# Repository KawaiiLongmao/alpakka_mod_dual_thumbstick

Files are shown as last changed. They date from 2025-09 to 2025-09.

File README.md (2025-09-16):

Development Board : rp2040 zero

初版：

GP20(Home)->GP13,GP18(CS0)->GP0,GP19(CS1)->GP1

led：上移12.5mm

r6电阻：左移21.5mm，上移4.75mm

home：上移22.5mm

滚轮：左移16mm

两摇杆间距：51.75mm

修订1：

GP20(Home)->GP13,GP18(CS0)->GP0,GP19(CS1)->GP1

led：上移12.5mm

r6电阻：左移21.5mm，上移4.75mm

home：上移22.5mm

滚轮：左移18.5mm

左摇杆：左移2.5mm

两摇杆间距：52mm

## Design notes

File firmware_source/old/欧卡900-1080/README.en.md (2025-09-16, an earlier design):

# 小改alpakka固件

#### Description
{**When you're done, you can delete the content in this README and update the file with details for others getting started with your repository**}

#### Software Architecture
Software architecture description

#### Installation

1.  xxxx
2.  xxxx
3.  xxxx

#### Instructions

1.  xxxx
2.  xxxx
3.  xxxx

#### Contribution

1.  Fork the repository
2.  Create Feat_xxx branch
3.  Commit your code
4.  Create Pull Request

#### Gitee Feature

1.  You can use Readme\_XXX.md to support different languages, such as Readme\_en.md, Readme\_zh.md
2.  Gitee blog [blog.gitee.com](https://blog.gitee.com)
3.  Explore open source project [https://gitee.com/explore](https://gitee.com/explore)
4.  The most valuable open source project [GVP](https://gitee.com/gvp)
5.  The manual of Gitee [https://gitee.com/help](https://gitee.com/help)
6.  The most popular members  [https://gitee.com/gitee-stars/](https://gitee.com/gitee-stars/)

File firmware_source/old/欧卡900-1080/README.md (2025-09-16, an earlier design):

欧卡固件：

为了兼容官方网页，方向盘角度是网页配置数值的6倍。

原本就有的问题：建议这么垫在键盘上校准，离平放手柄竖起来不要超过90度，不然会抽风。

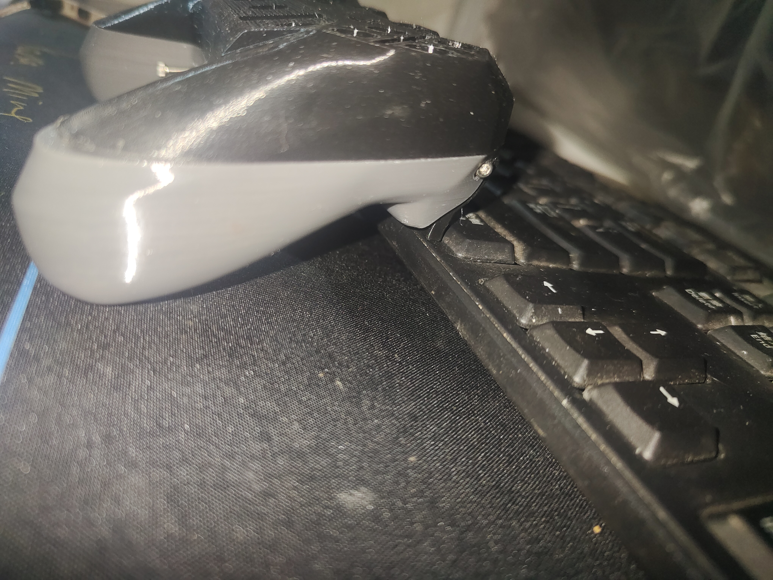
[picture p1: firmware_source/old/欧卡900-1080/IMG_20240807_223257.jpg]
输入图片说明


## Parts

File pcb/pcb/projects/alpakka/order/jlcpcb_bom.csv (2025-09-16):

Comment | Designator | Footprint | LCSC Part Number
Button front | S1,S10,S11,S12,S14,S2,S3,S4,S5,S6,S7,S8,S9 | SMD | C115348
R_500K | R6 | SMD | C11616
C_100nF | C1,C2,C3,C4,C5,C6,C7,C8 | SMD | C1525
Button back | S17,S18,S19,S20 | SMD | C202424
LED | D1,D2,D3,D4 | SMD | C2290
R_20 | R1,R2,R3,R4 | SMD | C22950
IO | U6,U8 | SMD | C2652287
Capacitive | P2 | SMD | C707322
IMU | U10,U12 | SMD | C784817

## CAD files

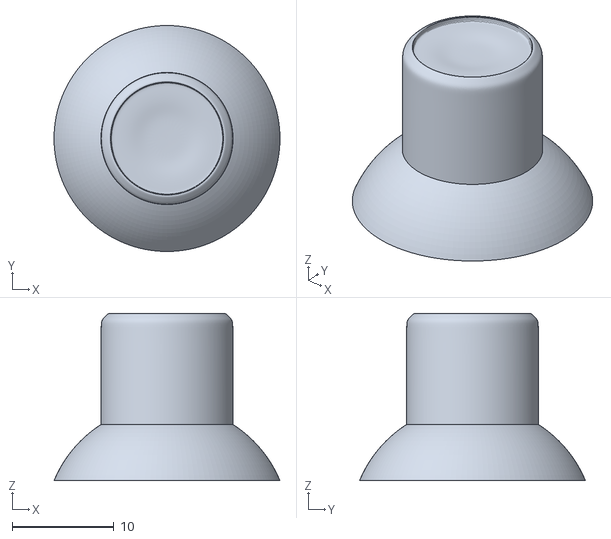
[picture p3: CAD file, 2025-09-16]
3d-model/Alpakka其他模型/摇杆，无顶，杆直径13mm，7mm/无顶矮超粗摇杆.stl
22.2 x 22.2 x 16.4

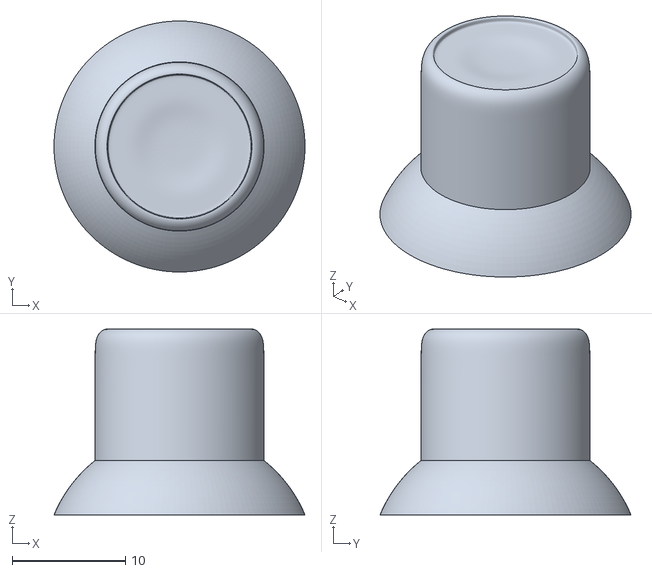
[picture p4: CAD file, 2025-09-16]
3d-model/Alpakka其他模型/摇杆，无顶，杆直径15mm，7mm/无顶矮超超粗摇杆.stl
22.2 x 22.2 x 16.4

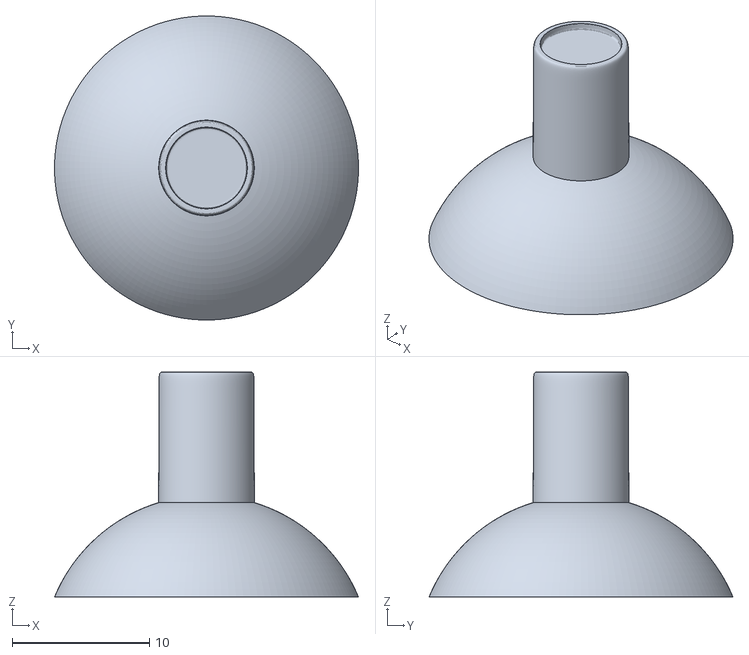
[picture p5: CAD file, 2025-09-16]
3d-model/Alpakka其他模型/摇杆，无顶，杆直径7mm，7mm/无顶矮摇杆.stl
22.2 x 22.2 x 16.4

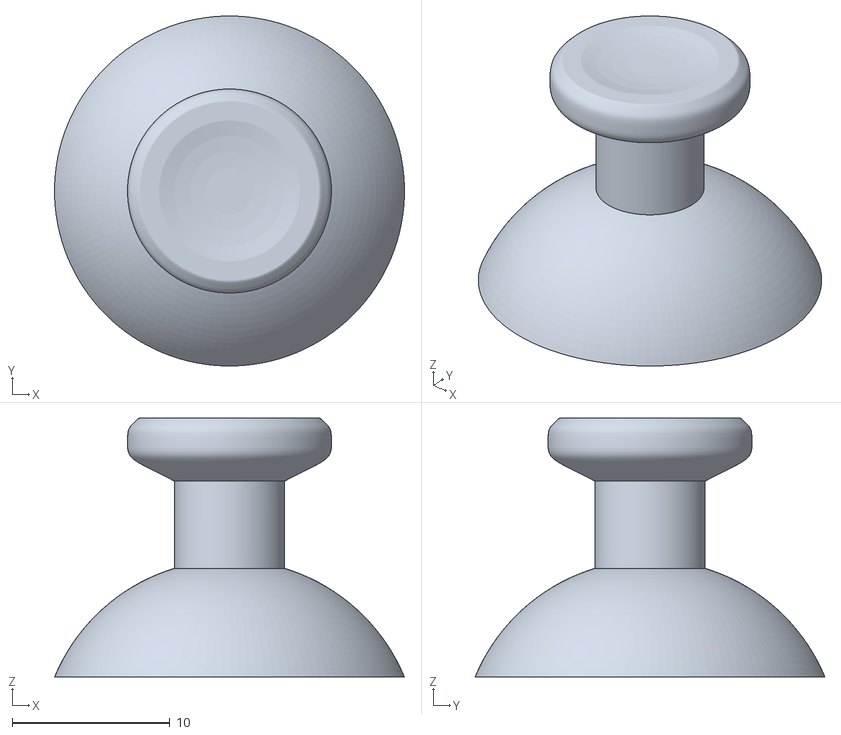
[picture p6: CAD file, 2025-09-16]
3d-model/Alpakka其他模型/摇杆，顶直径12mm，杆直径7mm，7mm/矮摇杆.stl
22.2 x 22.2 x 16.4

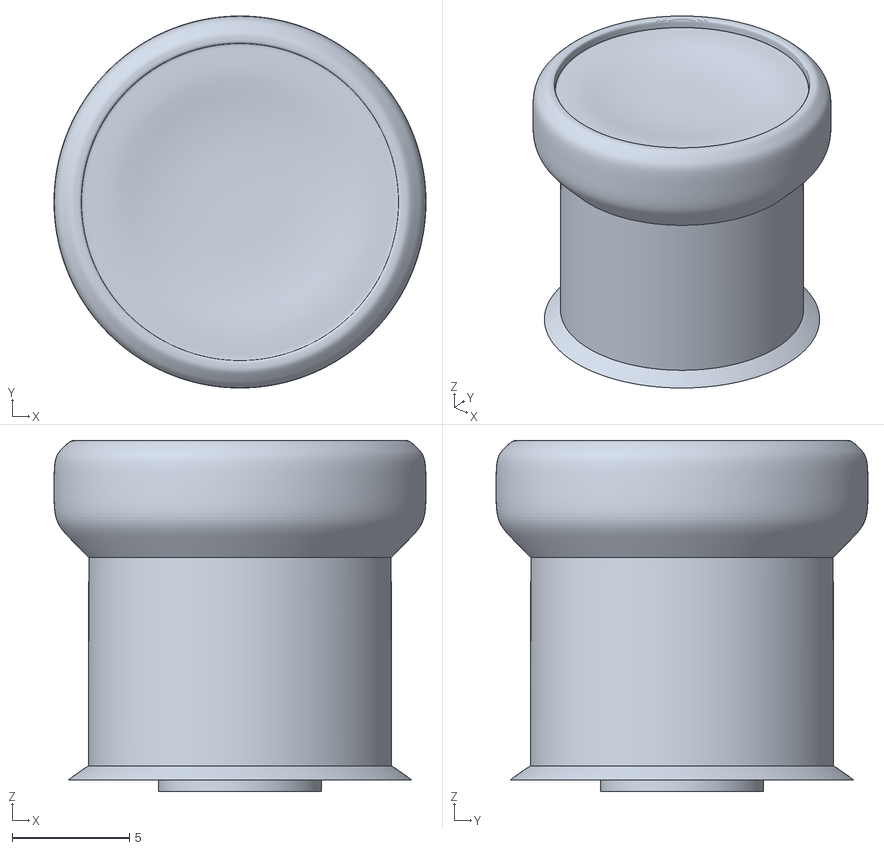
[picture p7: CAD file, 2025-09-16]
3d-model/Alpakka其他模型/摇杆，顶直径16mm，杆直径13mm，10mm/大顶高超粗摇杆.stl
15.9 x 15.9 x 15.0

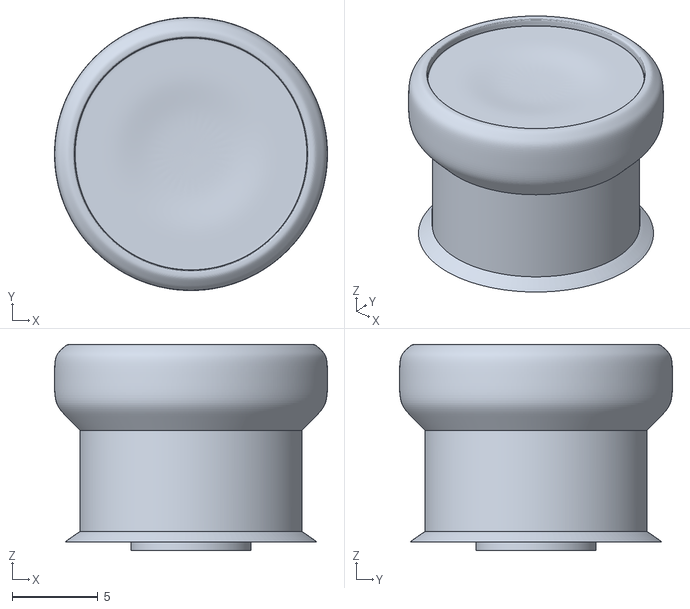
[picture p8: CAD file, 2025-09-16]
3d-model/Alpakka其他模型/摇杆，顶直径16mm，杆直径13mm，7mm/大顶矮超粗摇杆.stl
15.9 x 15.9 x 12.0

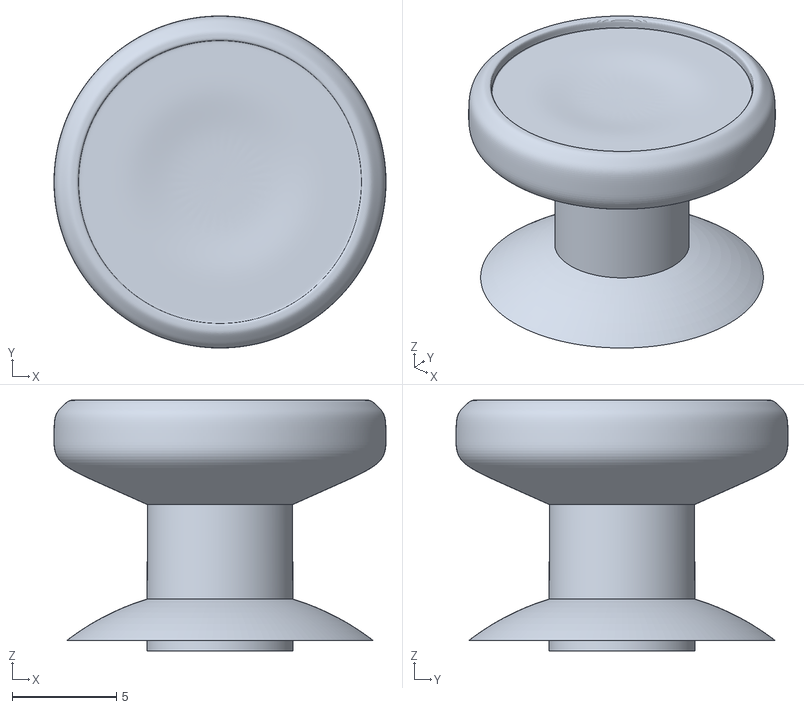
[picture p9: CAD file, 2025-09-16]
3d-model/Alpakka其他模型/摇杆，顶直径16mm，杆直径7mm，7mm/大顶矮摇杆.stl
15.9 x 15.9 x 12.0

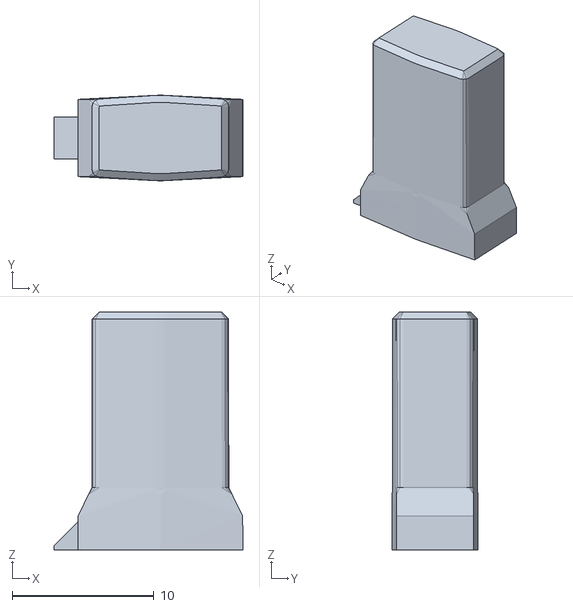
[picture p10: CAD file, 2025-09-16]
3d-model/Alpakka单双摇杆文件整理/Alpakka双摇杆home键.stl
13.3 x 6.06 x 16.8

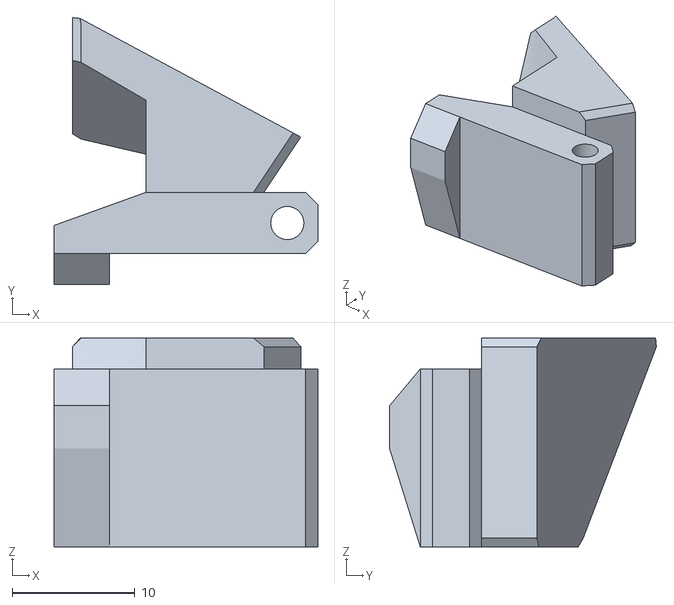
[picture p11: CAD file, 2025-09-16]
3d-model/Alpakka单双摇杆文件整理/剩下的官方文件/primary_015mm_trigger_R4.stl
21.5 x 21.7 x 17.0

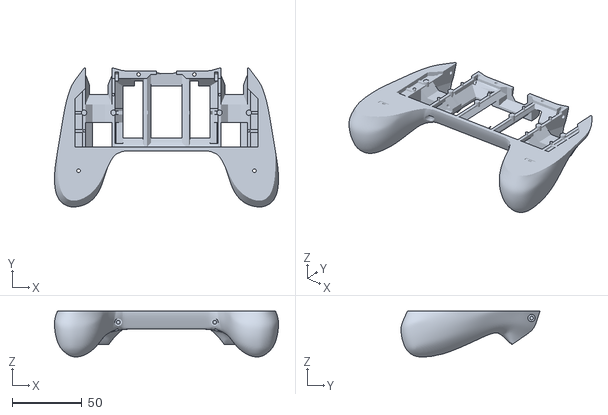
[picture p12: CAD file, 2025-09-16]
3d-model/Alpakka单双摇杆文件整理/单双摇杆共用/case_back.stl
160.4 x 99.5 x 32.9

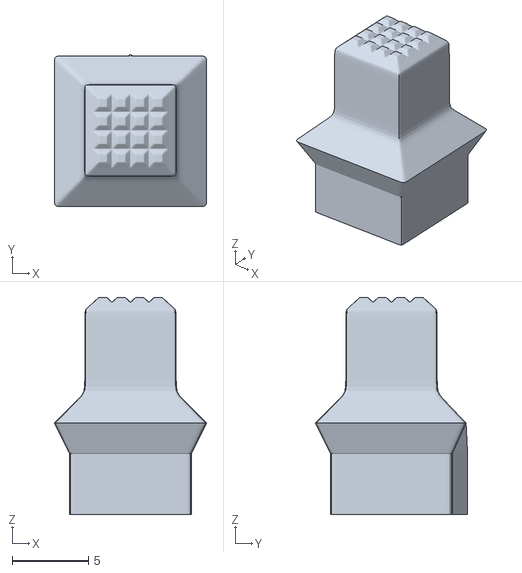
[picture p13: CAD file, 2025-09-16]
3d-model/Alpakka单摇杆[优化3][螺丝替代面板]/stl/dhat.stl
10.0 x 10.0 x 14.3

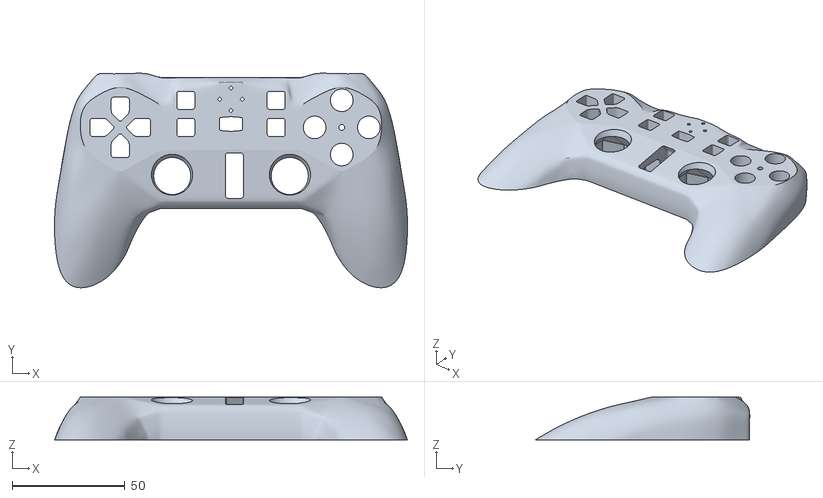
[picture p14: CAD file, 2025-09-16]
3d-model/Alpakka双摇杆[1.1.5][平整面壳][无八边形限位]/stl/case_front.stl
156.2 x 94.9 x 19.0

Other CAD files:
3d-model/Alpakka其他模型/摇杆，无顶，杆直径9mm，7mm/无顶矮粗摇杆.stl
3d-model/Alpakka其他模型/摇杆，顶直径12mm，杆直径9mm，7mm/矮粗摇杆.stl
3d-model/Alpakka其他模型/摇杆，顶直径16mm，杆直径7mm，10mm/大顶高摇杆.stl
3d-model/Alpakka其他模型/摇杆，顶直径16mm，杆直径9mm，10mm/大顶高粗摇杆.stl
3d-model/Alpakka其他模型/摇杆，顶直径16mm，杆直径9mm，7mm/大顶矮粗摇杆.stl
3d-model/Alpakka其他模型/导电面板，螺丝孔，去面板/button_abxy.blend
3d-model/Alpakka其他模型/导电面板，螺丝孔，去面板/hexagon_screwed.blend
3d-model/Alpakka其他模型/导电面板，螺丝孔，去面板/hexagon_screwed_去面板.stl
3d-model/Alpakka其他模型/导电面板，螺丝孔，去面板/shared.blend
3d-model/Alpakka其他模型/摇杆，无顶，杆直径13mm，7mm/shared.blend
3d-model/Alpakka其他模型/摇杆，无顶，杆直径13mm，7mm/thumbstick.blend
3d-model/Alpakka其他模型/摇杆，无顶，杆直径15mm，7mm/shared.blend
3d-model/Alpakka其他模型/摇杆，无顶，杆直径15mm，7mm/thumbstick.blend
3d-model/Alpakka其他模型/摇杆，无顶，杆直径7mm，7mm/shared.blend
3d-model/Alpakka其他模型/摇杆，无顶，杆直径7mm，7mm/thumbstick.blend
3d-model/Alpakka其他模型/摇杆，无顶，杆直径9mm，7mm/shared.blend
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

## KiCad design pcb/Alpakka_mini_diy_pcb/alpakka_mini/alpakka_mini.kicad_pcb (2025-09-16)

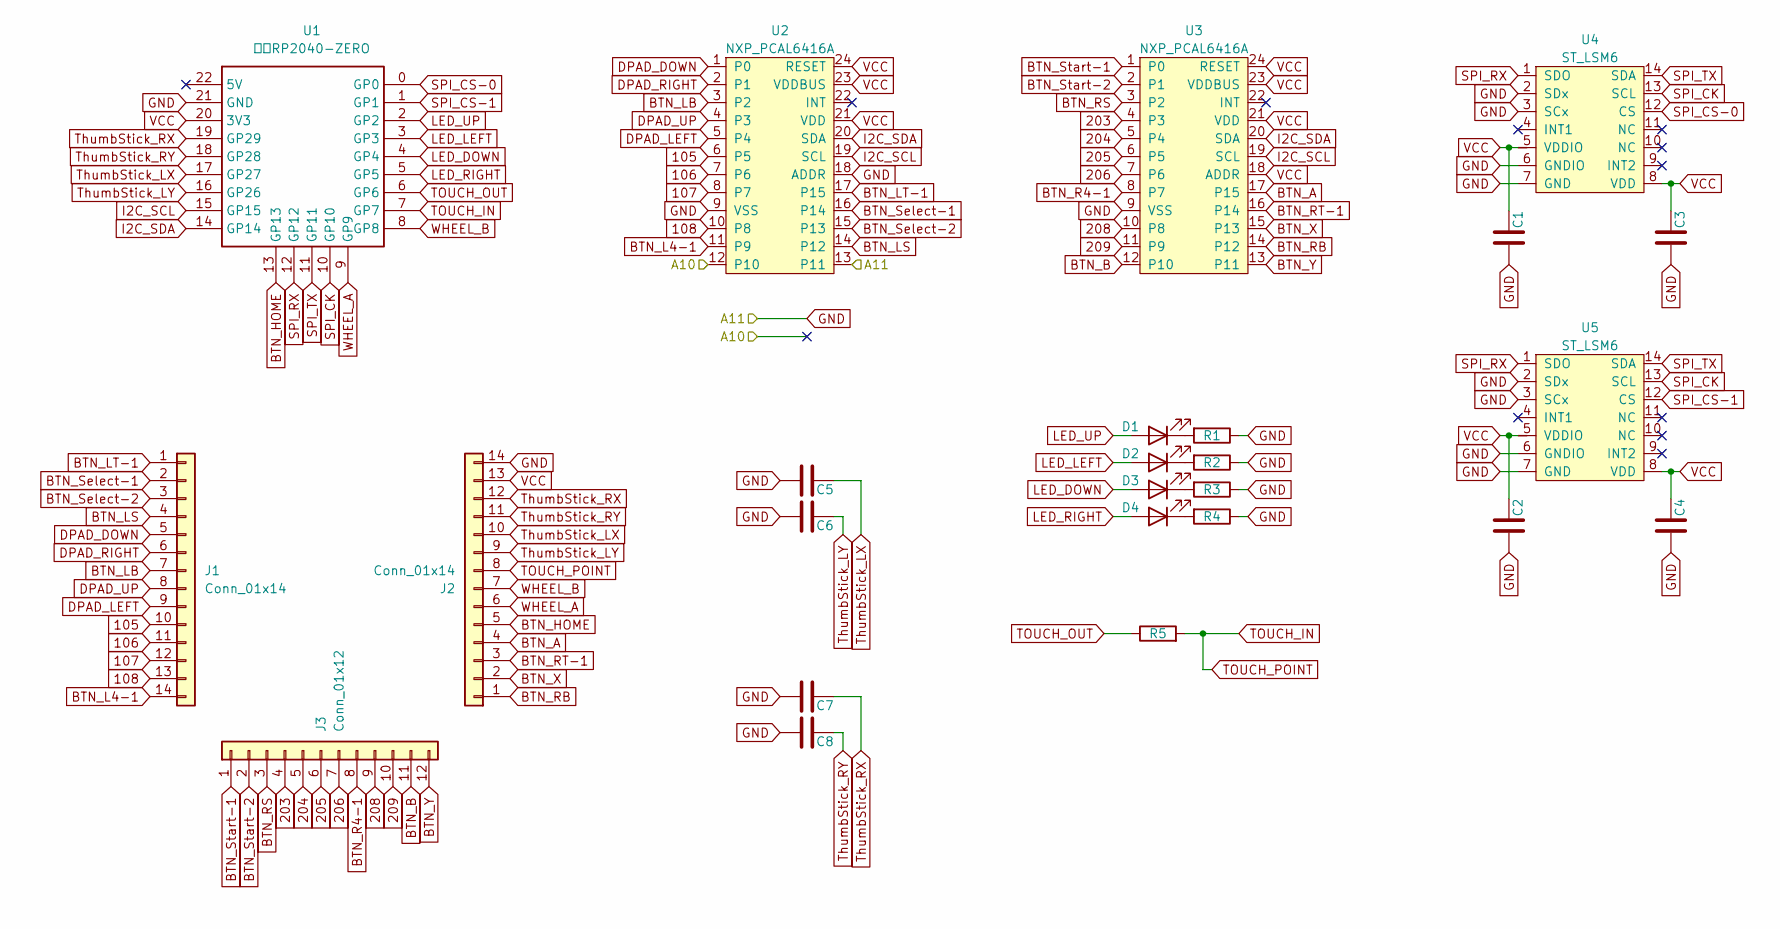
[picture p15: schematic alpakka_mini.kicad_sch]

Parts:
C1, C2, C3, C4, C5, C6, C7, C8: C; 0402; LCSC C1525
D1, D2, D3, D4: Diode; 0603_d; LCSC C2290
J1, J2: Conn_01x14; 邮票孔排针1x14PIN_2.54MM
J3: Conn_01x12; 邮票孔排针1x12PIN_2.54MM
R1, R2, R3, R4: R; 0603; LCSC C22950
R5: R6; 0402; LCSC C11616
U1: 微雪RP2040-ZERO; RP2040-ZERO_SMT
U2, U3: NXP_PCAL6416A; QFN24; LCSC C2652287
U4, U5: ST_LSM6; LGA14; LCSC C784817

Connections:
105: J1.10, U2.6 (P5)
106: J1.11, U2.7 (P6)
107: J1.12, U2.8 (P7)
108: J1.13, U2.10 (P8)
203: J3.4, U3.4 (P3)
204: J3.5, U3.5 (P4)
205: J3.6, U3.6 (P5)
206: J3.7, U3.7 (P6)
208: J3.9, U3.10 (P8)
209: J3.10, U3.11 (P9)
/A10: U2.12 (P10)
BTN_A: J2.4, U3.17 (P15)
BTN_B: J3.11, U3.12 (P10)
BTN_HOME: J2.5, U1.13 (GP13)
BTN_L4-1: J1.14, U2.11 (P9)
BTN_LB: J1.7, U2.3 (P2)
BTN_LS: J1.4, U2.14 (P12)
BTN_LT-1: J1.1, U2.17 (P15)
BTN_R4-1: J3.8, U3.8 (P7)
BTN_RB: J2.1, U3.14 (P12)
BTN_RS: J3.3, U3.3 (P2)
BTN_RT-1: J2.3, U3.16 (P14)
BTN_Select-1: J1.2, U2.16 (P14)
BTN_Select-2: J1.3, U2.15 (P13)
BTN_Start-1: J3.1, U3.1 (P0)
BTN_Start-2: J3.2, U3.2 (P1)
BTN_X: J2.2, U3.15 (P13)
BTN_Y: J3.12, U3.13 (P11)
DPAD_DOWN: J1.5, U2.1 (P0)
DPAD_LEFT: J1.9, U2.5 (P4)
DPAD_RIGHT: J1.6, U2.2 (P1)
DPAD_UP: J1.8, U2.4 (P3)
GND: C1.1, C2.1, C3.1, C4.1, C5.1, C6.1, C7.1, C8.1, J2.14, R1.1, R2.1, R3.1, R4.1, U1.21 (GND), U2.9 (VSS), U2.13 (P11), U2.18 (ADDR), U3.9 (VSS), U4.2 (SDx), U4.3 (SCx), U4.6 (GNDIO), U4.7 (GND), U5.2 (SDx), U5.3 (SCx), U5.6 (GNDIO), U5.7 (GND)
I2C_SCL: U1.15 (GP15), U2.19 (SCL), U3.19 (SCL)
I2C_SDA: U1.14 (GP14), U2.20 (SDA), U3.20 (SDA)
LED_DOWN: D3.2 (A), U1.4 (GP4)
LED_LEFT: D2.2 (A), U1.3 (GP3)
LED_RIGHT: D4.2 (A), U1.5 (GP5)
LED_UP: D1.2 (A), U1.2 (GP2)
unnamed: D1.1 (K), R1.2
unnamed: D2.1 (K), R2.2
unnamed: D3.1 (K), R3.2
unnamed: D4.1 (K), R4.2
SPI_CK: U1.10 (GP10), U4.13 (SCL), U5.13 (SCL)
SPI_CS-0: U1.0 (GP0), U4.12 (CS)
SPI_CS-1: U1.1 (GP1), U5.12 (CS)
SPI_RX: U1.12 (GP12), U4.1 (SDO), U5.1 (SDO)
SPI_TX: U1.11 (GP11), U4.14 (SDA), U5.14 (SDA)
TOUCH_IN: J2.8, R5.2, U1.7 (GP7)
TOUCH_OUT: R5.1, U1.6 (GP6)
ThumbStick_LX: C5.2, J2.10, U1.17 (GP27)
ThumbStick_LY: C6.2, J2.9, U1.16 (GP26)
ThumbStick_RX: C7.2, J2.12, U1.19 (GP29)
ThumbStick_RY: C8.2, J2.11, U1.18 (GP28)
VCC: C1.2, C2.2, C3.2, C4.2, J2.13, U1.20 (3V3), U2.21 (VDD), U2.23 (VDDBUS), U2.24 (RESET), U3.18 (ADDR), U3.21 (VDD), U3.23 (VDDBUS), U3.24 (RESET), U4.5 (VDDIO), U4.8 (VDD), U5.5 (VDDIO), U5.8 (VDD)
WHEEL_A: J2.6, U1.9 (GP9)
WHEEL_B: J2.7, U1.8 (GP8)

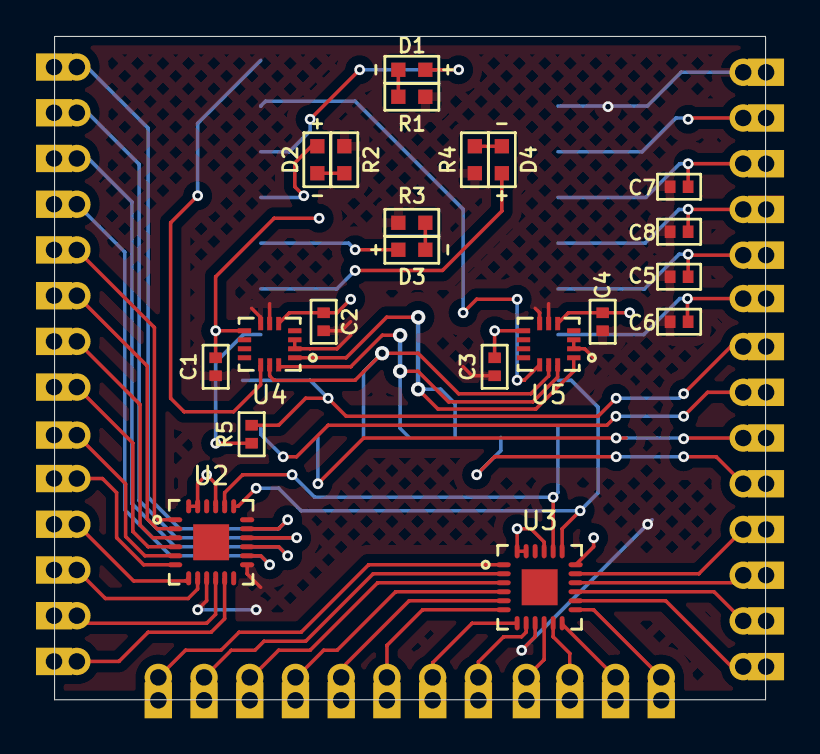
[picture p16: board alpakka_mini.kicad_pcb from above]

Board: 2 copper layers, 39.5 x 36.9 mm, 25 parts (1 on the bottom side), 56 nets.

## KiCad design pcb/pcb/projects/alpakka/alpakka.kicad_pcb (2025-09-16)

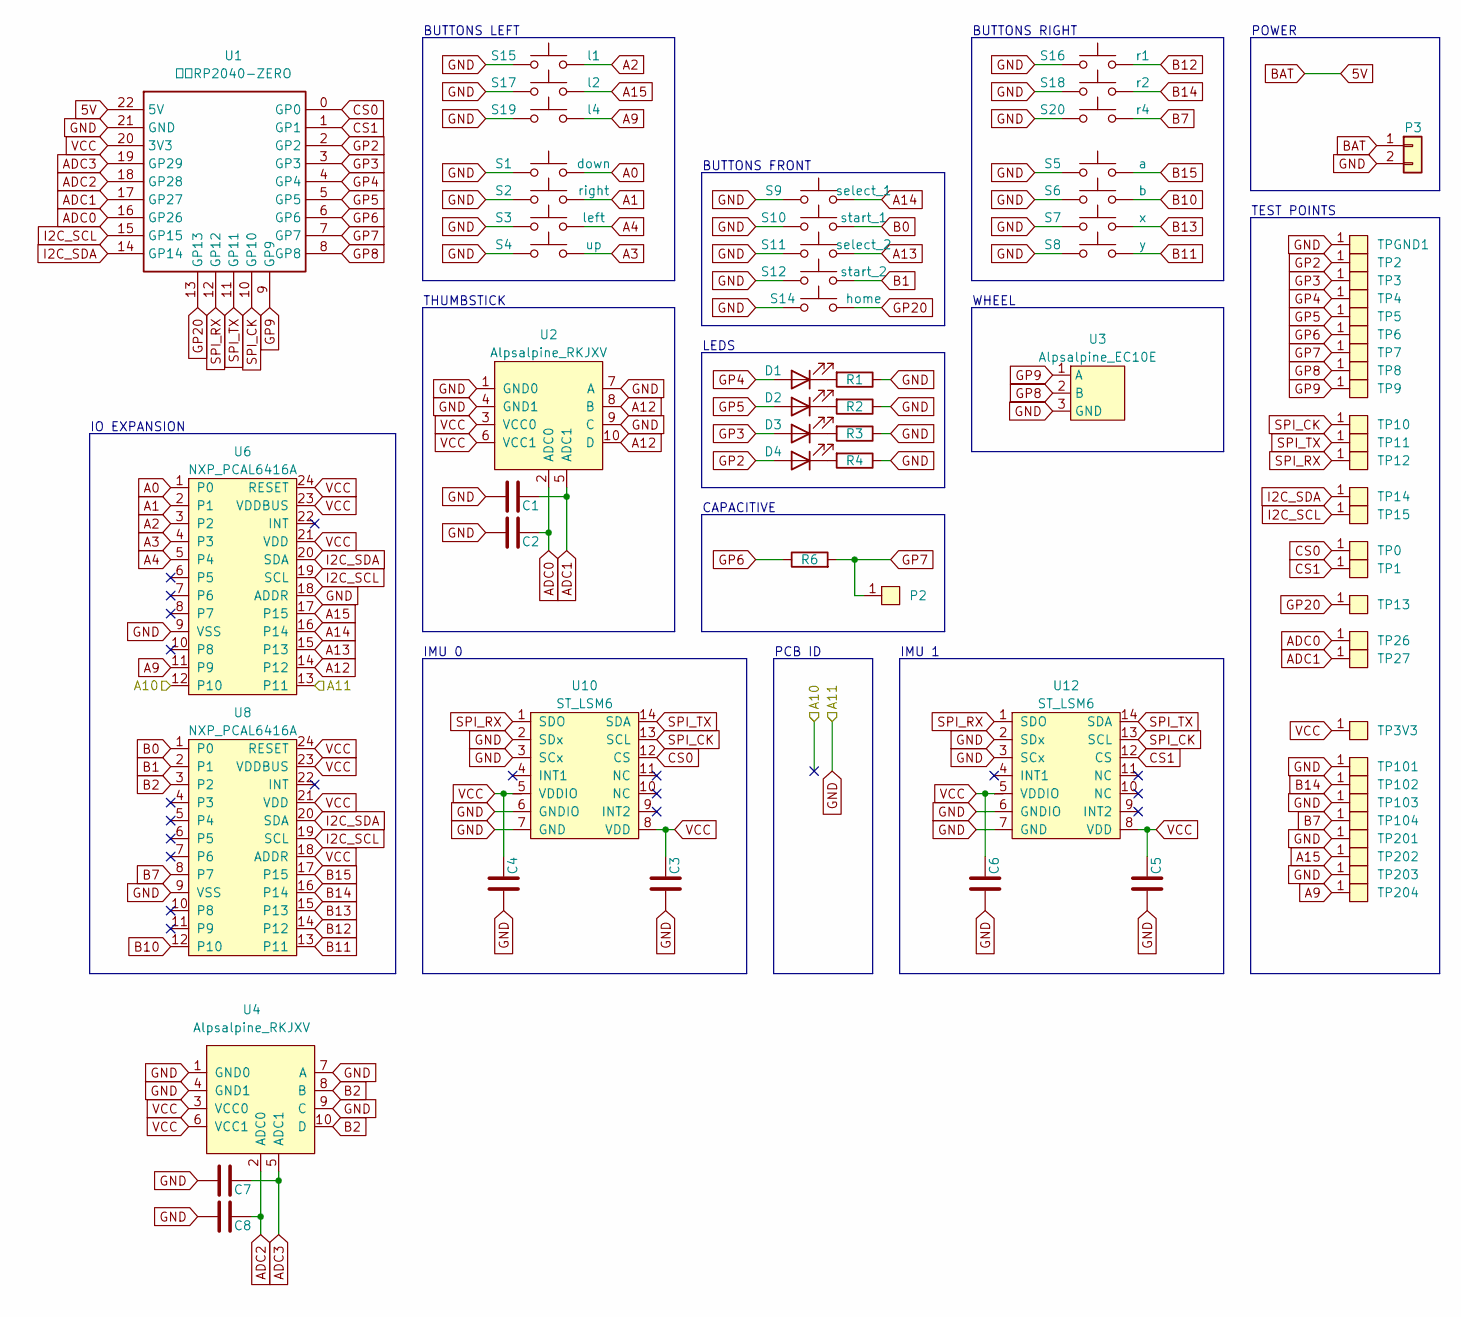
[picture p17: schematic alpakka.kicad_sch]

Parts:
C1, C2, C3, C4, C5, C6, C7, C8: C; 0402; LCSC C1525
D1, D2, D3, D4: Diode; 0603_d; LCSC C2290
P2: Endpoint; HRO_BC-25-3P; LCSC C707322
P3: Conn_01x02; JST_PH_2_TH
R1, R2, R3, R4: R; 0603; LCSC C22950
R6: R6; 0402; LCSC C11616
S1: down; Alpsalpine_SKPM; LCSC C115348
S2: right; Alpsalpine_SKPM; LCSC C115348
S3: left; Alpsalpine_SKPM; LCSC C115348
S4: up; Alpsalpine_SKPM; LCSC C115348
S5: a; Alpsalpine_SKPM; LCSC C115348
S6: b; Alpsalpine_SKPM; LCSC C115348
S7: x; Alpsalpine_SKPM; LCSC C115348
S8: y; Alpsalpine_SKPM; LCSC C115348
S9: select_1; Alpsalpine_SKPM; LCSC C115348
S10: start_1; Alpsalpine_SKPM; LCSC C115348
S11: select_2; Alpsalpine_SKPM; LCSC C115348
S12: start_2; Alpsalpine_SKPM; LCSC C115348
S14: home; Alpsalpine_SKPM; LCSC C115348
S15: l1; Alpsalpine_SKHHL; LCSC C125031
S16: r1; Alpsalpine_SKHHL; LCSC C125031
S17: l2; Alpsalpine_SKQG; LCSC C202424
S18: r2; Alpsalpine_SKQG; LCSC C202424
S19: l4; Alpsalpine_SKQG; LCSC C202424
S20: r4; Alpsalpine_SKQG; LCSC C202424
TP0, TP1, TP2, TP3, TP3V3, TP4, TP5, TP6, TP7, TP8, TP9, TP10, TP11, TP12, TP13, TP14, TP15, TP26, TP27, TP101, TP102, TP103, TP104, TP201, TP202, TP203, TP204: Endpoint; Pad_1mm
TPGND1: Endpoint; Pad_1mm
U1: 微雪RP2040-ZERO; PICOMINI
U2: Alpsalpine_RKJXV; Alpsalpine_RKJXV122400R; LCSC C918854
U3: Alpsalpine_EC10E; LCSC C110291
U4: Alpsalpine_RKJXV; Alpsalpine_RKJXV122400R
U6, U8: NXP_PCAL6416A; QFN24; LCSC C2652287
U10, U12: ST_LSM6; LGA14; LCSC C784817

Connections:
5V: P3.1, U1.22 (5V)
/A10: U6.12 (P10)
A0: S1.2, U6.1 (P0)
A1: S2.2, U6.2 (P1)
A2: S15.2, U6.3 (P2)
A3: S4.2, U6.4 (P3)
A4: S3.2, U6.5 (P4)
A9: S19.2, TP204.1, U6.11 (P9)
A12: U2.8 (B), U2.10 (D), U6.14 (P12)
A13: S11.2, U6.15 (P13)
A14: S9.2, U6.16 (P14)
A15: S17.2, TP202.1, U6.17 (P15)
ADC0: C2.2, TP26.1, U1.16 (GP26), U2.2 (ADC0)
ADC1: C1.2, TP27.1, U1.17 (GP27), U2.5 (ADC1)
ADC2: C8.2, U1.18 (GP28), U4.2 (ADC0)
ADC3: C7.2, U1.19 (GP29), U4.5 (ADC1)
B0: S10.2, U8.1 (P0)
B1: S12.2, U8.2 (P1)
B2: U4.8 (B), U4.10 (D), U8.3 (P2)
B7: S20.2, TP104.1, U8.8 (P7)
B10: S6.2, U8.12 (P10)
B11: S8.2, U8.13 (P11)
B12: S16.2, U8.14 (P12)
B13: S7.2, U8.15 (P13)
B14: S18.2, TP102.1, U8.16 (P14)
B15: S5.2, U8.17 (P15)
CS0: TP0.1, U1.0 (GP0), U10.12 (CS)
CS1: TP1.1, U1.1 (GP1), U12.12 (CS)
GND: C1.1, C2.1, C3.1, C4.1, C5.1, C6.1, C7.1, C8.1, P3.2, R1.1, R2.1, R3.1, R4.1, S1.1, S2.1, S3.1, S4.1, S5.1, S6.1, S7.1, S8.1, S9.1, S10.1, S11.1, S12.1, S14.1, S15.1, S16.1, S17.1, S18.1, S19.1, S20.1, TP101.1, TP103.1, TP201.1, TP203.1, TPGND1.1, U1.21 (GND), U2.1 (GND0), U2.4 (GND1), U2.7 (A), U2.9 (C), U3.3 (GND), U4.1 (GND0), U4.4 (GND1), U4.7 (A), U4.9 (C), U6.9 (VSS), U6.13 (P11), U6.18 (ADDR), U8.9 (VSS), U10.2 (SDx), U10.3 (SCx), U10.6 (GNDIO), U10.7 (GND), U12.2 (SDx), U12.3 (SCx), U12.6 (GNDIO), U12.7 (GND)
GP2: D4.2 (A), TP2.1, U1.2 (GP2)
GP3: D3.2 (A), TP3.1, U1.3 (GP3)
GP4: D1.2 (A), TP4.1, U1.4 (GP4)
GP5: D2.2 (A), TP5.1, U1.5 (GP5)
GP6: R6.1, TP6.1, U1.6 (GP6)
GP7: P2.1, R6.2, TP7.1, U1.7 (GP7)
GP8: TP8.1, U1.8 (GP8), U3.2 (B)
GP9: TP9.1, U1.9 (GP9), U3.1 (A)
GP20: S14.2, TP13.1, U1.13 (GP13)
I2C_SCL: TP15.1, U1.15 (GP15), U6.19 (SCL), U8.19 (SCL)
I2C_SDA: TP14.1, U1.14 (GP14), U6.20 (SDA), U8.20 (SDA)
unnamed: D1.1 (K), R1.2
unnamed: D2.1 (K), R2.2
unnamed: D3.1 (K), R3.2
unnamed: D4.1 (K), R4.2
SPI_CK: TP10.1, U1.10 (GP10), U10.13 (SCL), U12.13 (SCL)
SPI_RX: TP12.1, U1.12 (GP12), U10.1 (SDO), U12.1 (SDO)
SPI_TX: TP11.1, U1.11 (GP11), U10.14 (SDA), U12.14 (SDA)
VCC: C3.2, C4.2, C5.2, C6.2, TP3V3.1, U1.20 (3V3), U2.3 (VCC0), U2.6 (VCC1), U4.3 (VCC0), U4.6 (VCC1), U6.21 (VDD), U6.23 (VDDBUS), U6.24 (RESET), U8.18 (ADDR), U8.21 (VDD), U8.23 (VDDBUS), U8.24 (RESET), U10.5 (VDDIO), U10.8 (VDD), U12.5 (VDDIO), U12.8 (VDD)

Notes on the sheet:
WHEEL
THUMBSTICK
IMU 0
PCB ID
IMU 1
BUTTONS FRONT
TEST POINTS
CAPACITIVE
IO EXPANSION
LEDS
BUTTONS LEFT
BUTTONS RIGHT
POWER

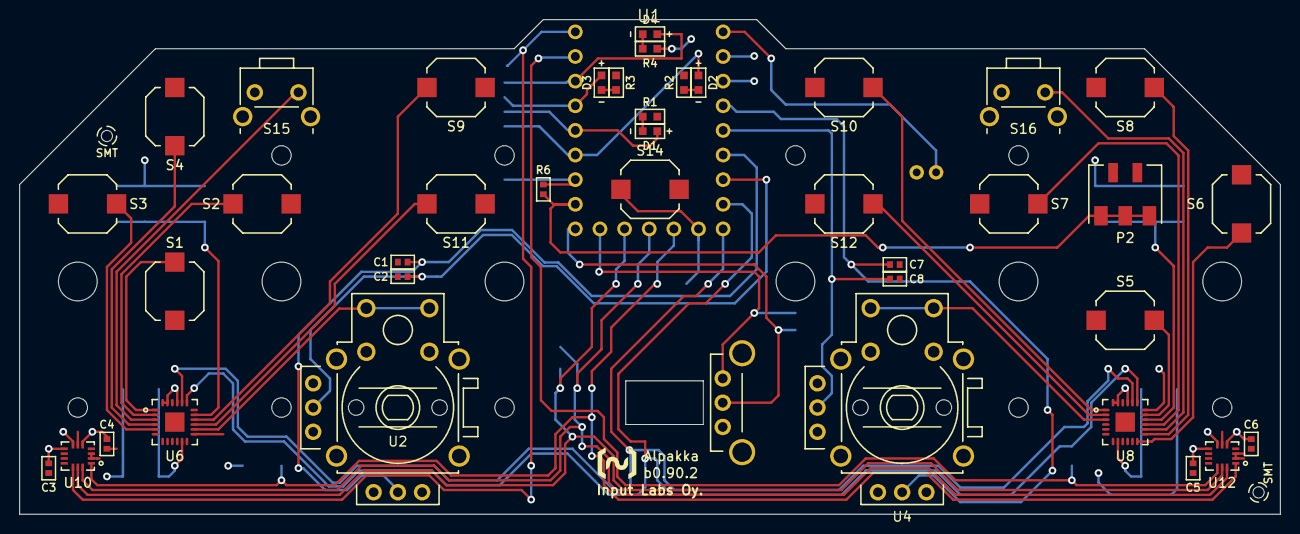
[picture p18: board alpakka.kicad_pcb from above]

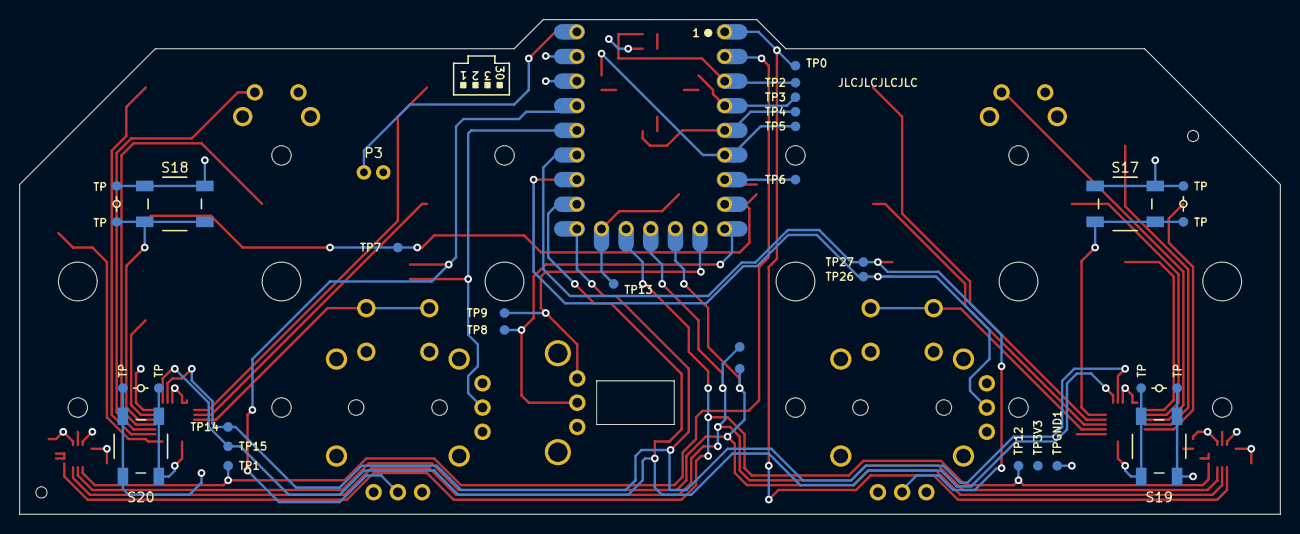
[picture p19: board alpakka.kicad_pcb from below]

Board: 2 copper layers, 130.0 x 51.0 mm, 74 parts (34 on the bottom side), 47 nets.
